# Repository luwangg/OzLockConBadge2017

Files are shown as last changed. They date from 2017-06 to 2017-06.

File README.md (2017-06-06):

# OzLockConBadge2017
Hardware and Firmware for the OzLockCon2017 Badge

Derived from the uDuck:
https://github.com/insecurityofthings/uDuck - as you can probably tell from the source code.

The hardware *may* support the uDuck firmware as the circuit is based off it - but i screwed something up and it doesn't want to work.
Ran out of time to debug so focused on the flashy flashy.

# Warning!
don't solder the USB connector onto the badge until you check the pin out! 
i screwed up and reversed the pads on the footprint - again...

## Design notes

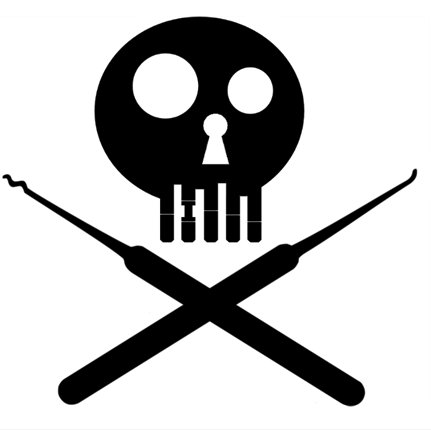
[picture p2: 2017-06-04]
hardware/OzLockCon.jpg

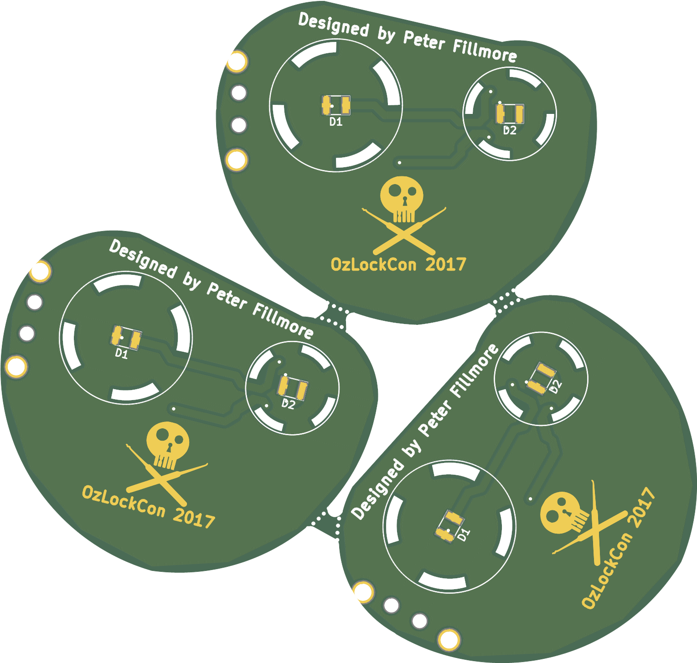
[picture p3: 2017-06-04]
hardware/Final/Final_Combined_Bottom.png

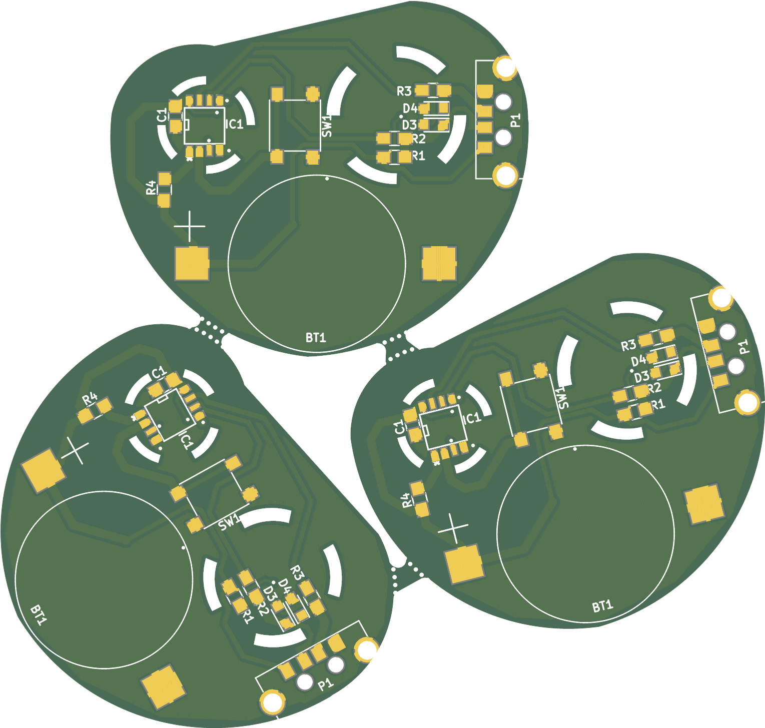
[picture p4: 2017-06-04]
hardware/Final/Final_Combined_Top.png

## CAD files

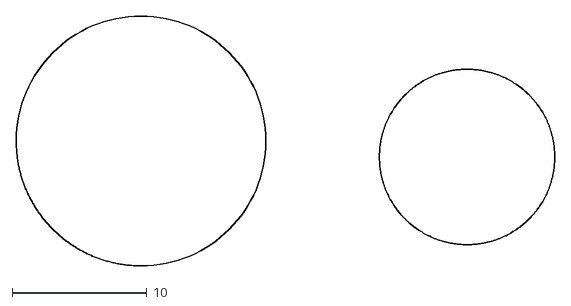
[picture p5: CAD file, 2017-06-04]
hardware/MechanicalView.dxf
40.0 x 18.5

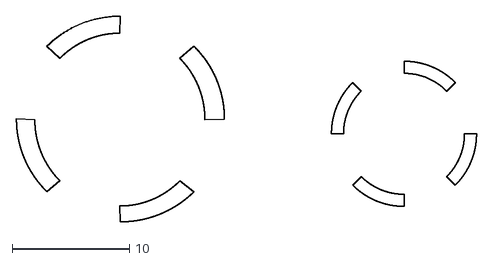
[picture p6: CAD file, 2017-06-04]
hardware/holes.dxf
39.2 x 17.5

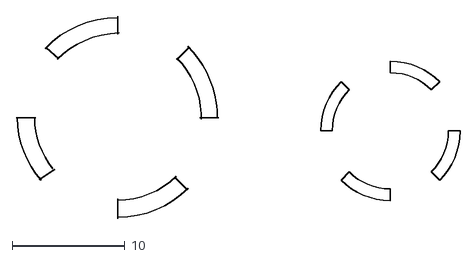
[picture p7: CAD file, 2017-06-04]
hardware/CutoutView.dxf
39.4 x 18.0

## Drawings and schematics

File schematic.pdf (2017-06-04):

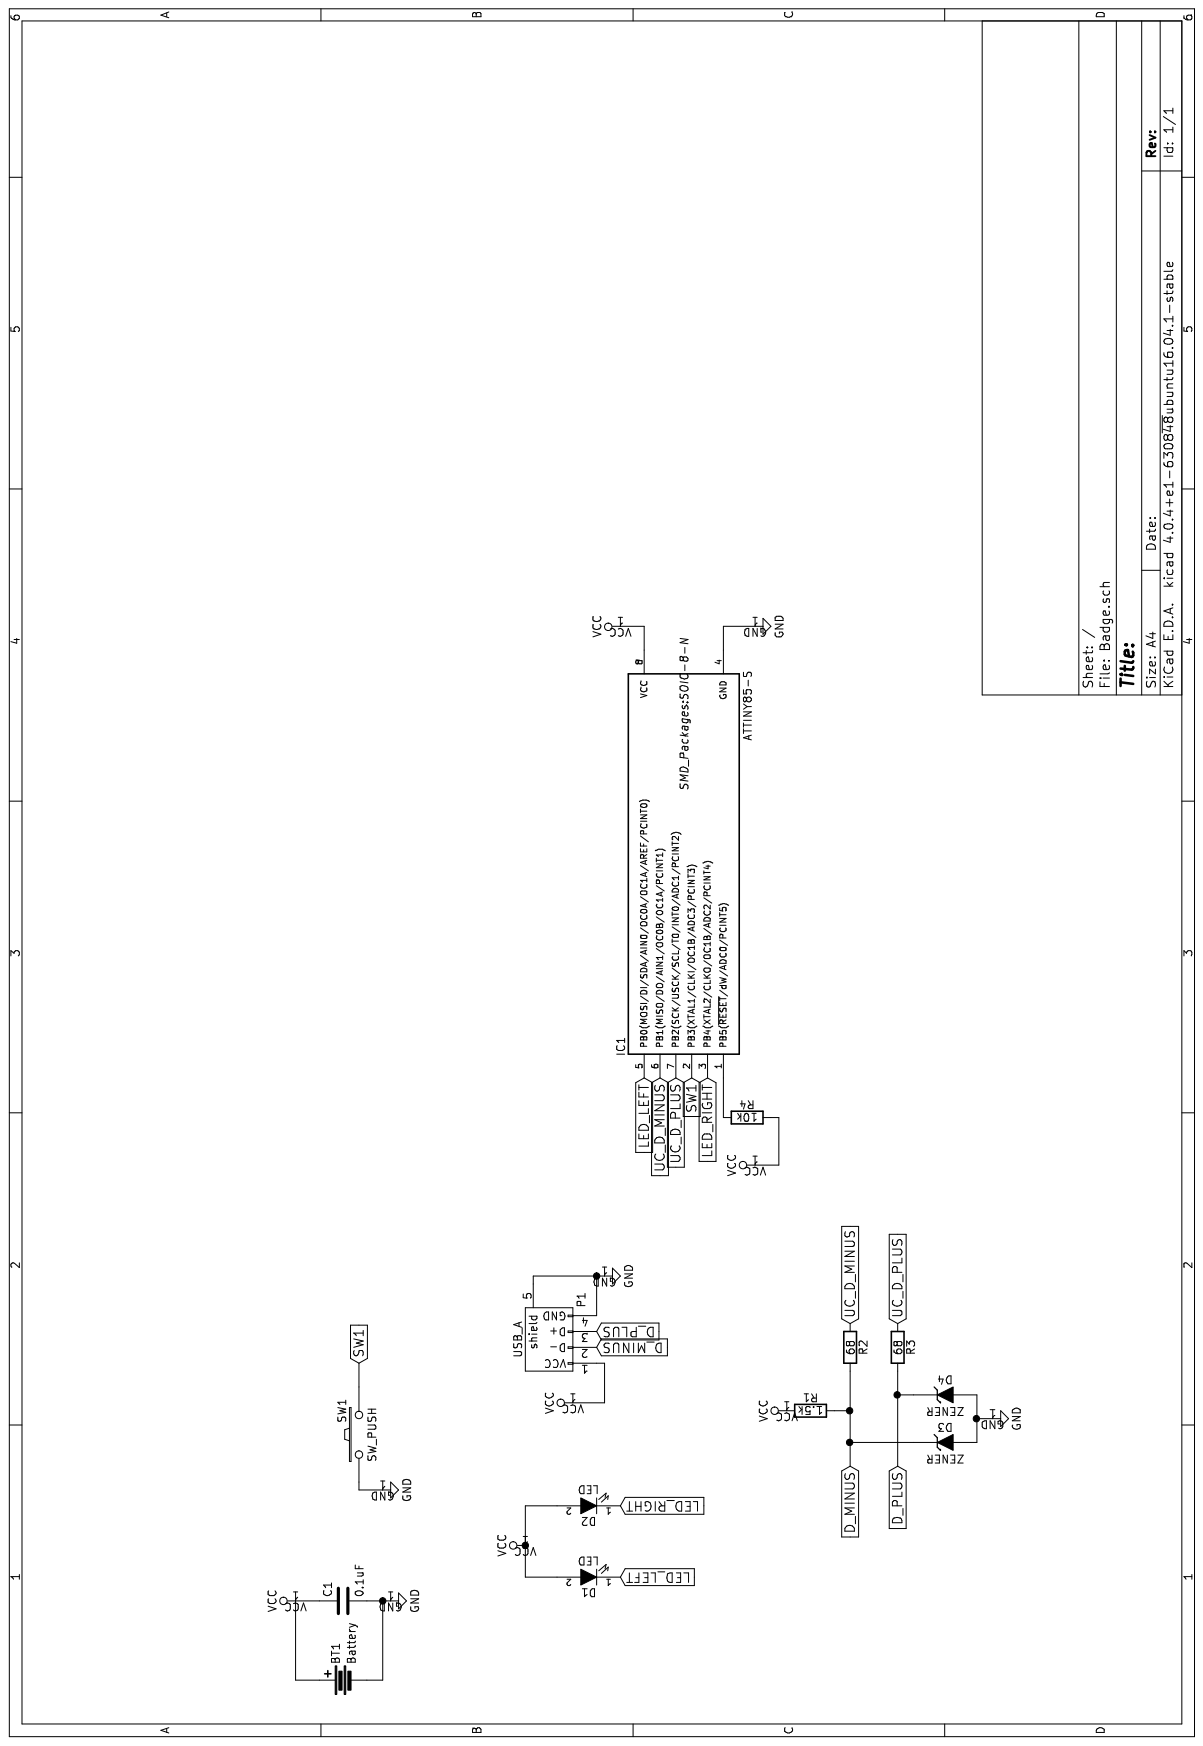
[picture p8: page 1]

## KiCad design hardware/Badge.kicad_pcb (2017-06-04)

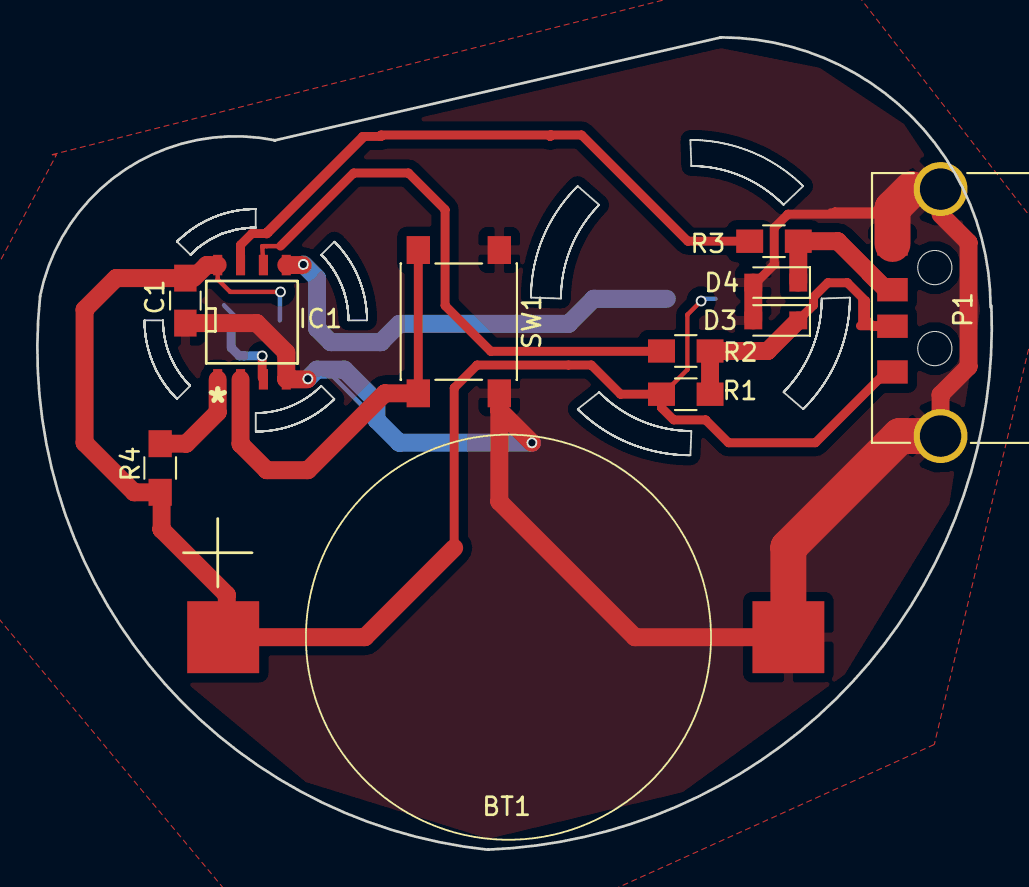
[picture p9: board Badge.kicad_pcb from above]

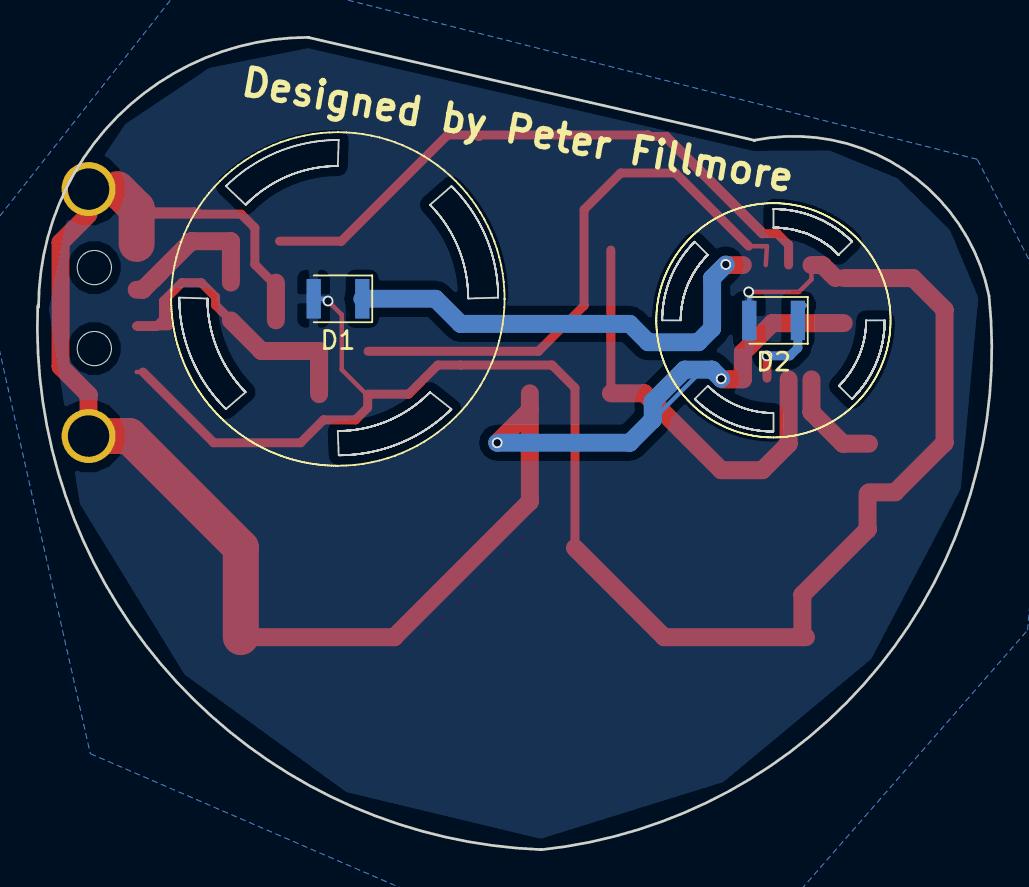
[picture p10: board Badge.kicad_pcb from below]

Board: 2 copper layers, 53.0 x 45.1 mm, 13 parts (2 on the bottom side), 10 nets.

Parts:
BT1: Battery; CR2032_SMD
C1: 0.1uF; C_0805_HandSoldering
D1, D2: LED; LED_3528
D3, D4: ZENER; D_SOD-323_HandSoldering
IC1: ATTINY85-S; SOIC-8-N
P1: USB_A; USB_A_SMD
R1: 1.5k; R_0805_HandSoldering
R2, R3: 68; R_0805_HandSoldering
R4: 10k; R_0805_HandSoldering
SW1: SW_PUSH; SW_SPST_PTS645

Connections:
D_MINUS: D3.1, P1.2, R1.2, R2.2
D_PLUS: D4.1, P1.3, R3.2
GND: BT1.2, C1.2, D3.2, D4.2, IC1.4, P1.4, P1.5, SW1.1
LED_LEFT: D1.1, IC1.5
LED_RIGHT: D2.1, IC1.3
unnamed: IC1.1, R4.1
SW1: IC1.2, SW1.2
UC_D_MINUS: IC1.6, R2.1
UC_D_PLUS: IC1.7, R3.1
VCC: BT1.1, C1.1, D1.2, D2.2, IC1.8, P1.1, R1.1, R4.2

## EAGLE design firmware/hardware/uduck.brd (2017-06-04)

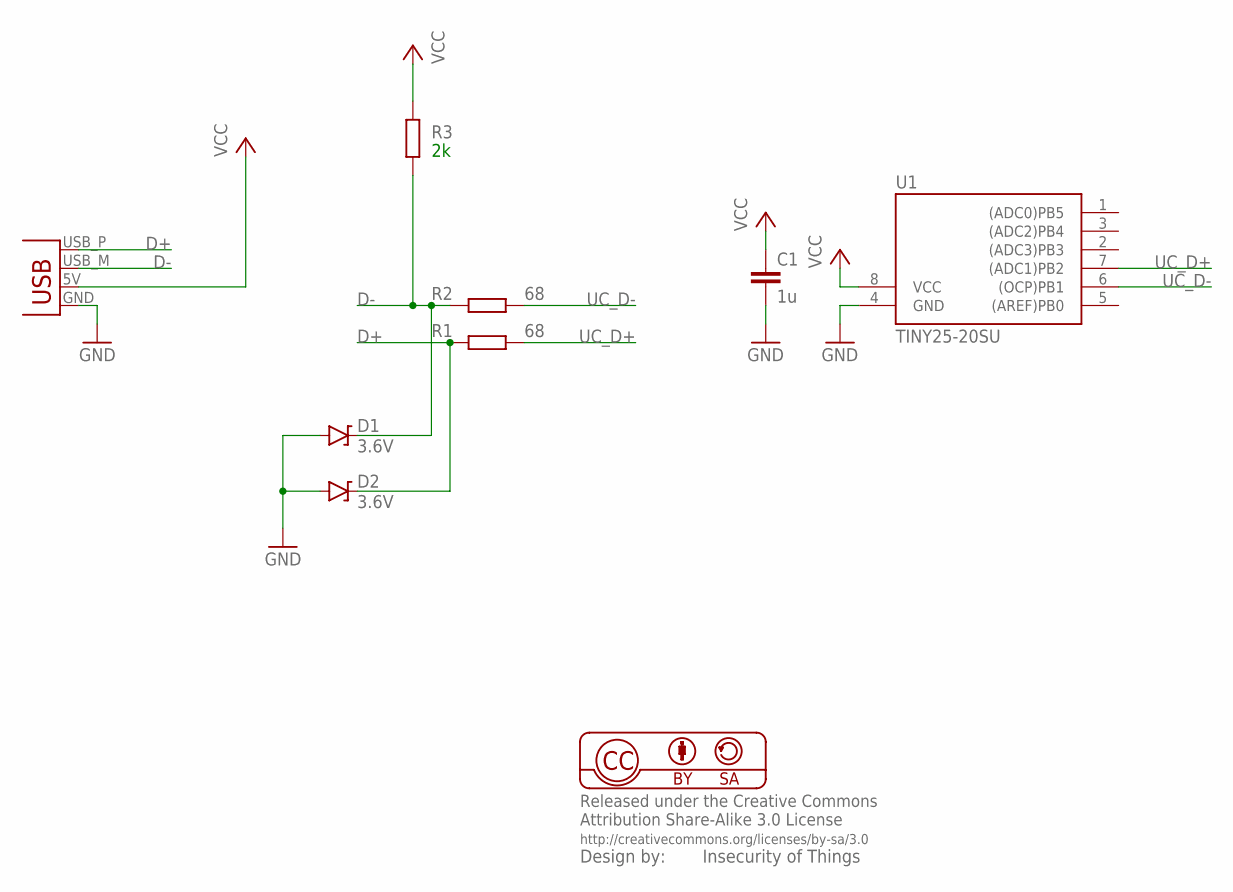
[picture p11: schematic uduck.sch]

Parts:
C1: 1u; C0805
D1, D2: 3.6V; SOD-323
R1, R2: 68; R0603
R3: 2k; R0603
U1: TINY25-20SU; SOIC8
X1: USBPCB; USB-A-PCB

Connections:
D+: D2.C, R1.2, X1.USB_P (D+)
D-: D1.C, R2.2, R3.1, X1.USB_M (D-)
GND: C1.2, D1.A, D2.A, U1.4 (GND), X1.GND
UC_D+: R1.1, U1.7 ((ADC1)PB2)
UC_D-: R2.1, U1.6 ((OCP)PB1)
VCC: C1.1, R3.2, U1.8 (VCC), X1.5V (VBUS)

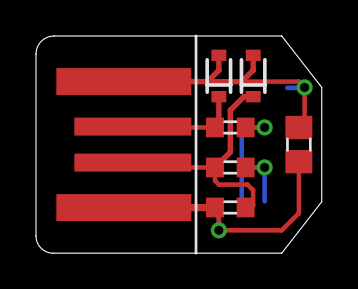
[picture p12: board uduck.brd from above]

Board: 2 copper layers, 15.9 x 12.1 mm, 8 parts (1 on the bottom side), 6 nets.

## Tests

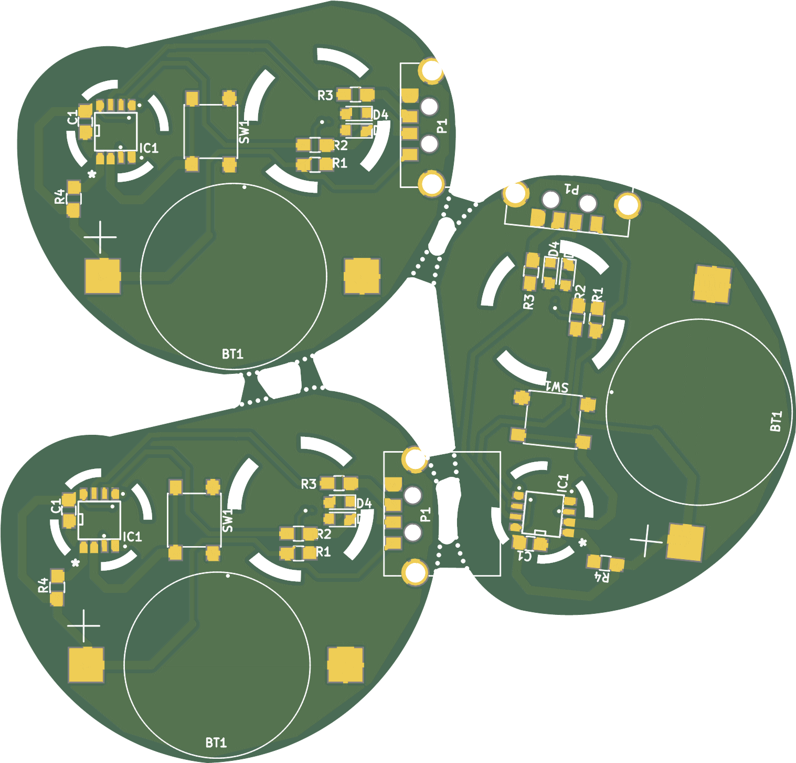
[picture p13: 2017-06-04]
hardware/Panelization/Test_Combined_Top.png

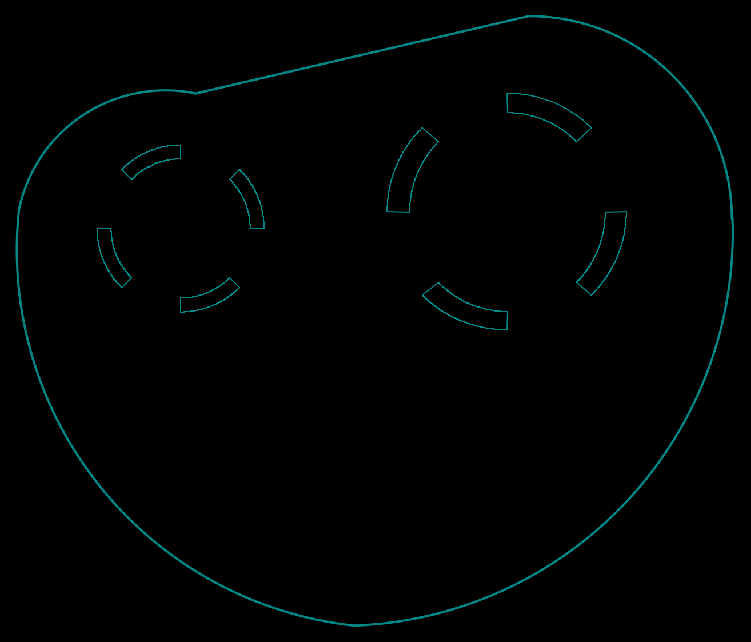
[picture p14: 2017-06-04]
hardware/Verification/edge.png

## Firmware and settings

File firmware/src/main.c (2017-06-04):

#include <avr/io.h>
#include <avr/wdt.h>
#include <avr/eeprom.h>
#include <avr/interrupt.h>
#include <avr/pgmspace.h>
#include <util/delay.h>
#include <stdlib.h>

//#include "usbdrv.h"
//#include "oddebug.h"

#define LED_LEFT 0b00000001
#define LED_RIGHT 0b00010000
#define SW1 0b00001000

volatile unsigned int mode_counter = 0;


ISR(PCINT0_vect) {
    //_delay_ms(50);   //wait for half second
   // PORTB ^= ~0b11101110;       //turn both LEDs off 
    if(mode_counter < 16) { 
        mode_counter++;
    }
    else{
        mode_counter = 0;
    }
    //PORTB ^=  0b00010001;       //turn LED off 
    _delay_ms(20); 
}

void setup() {
    GIMSK = 0b00100000;    // turns on pin change interrupts
    PCMSK = 0b00001000;    // turn on interrupts on pins PB3    
    sei();
    //DDRB = 0x00;         //PB as output
    //PORTB &= ~0x00;         //keep all LEDs off}
    DDRB |= _BV(PORTB0);         // OC0A
    //DDRB |= _BV(PORTB1);        // OC0B
    DDRB |= _BV(PORTB4);        // OC1B
    DDRB |= _BV(PORTB3);

    PORTB |= 0b00001000;         //enable pull-ups


  // Timer 0, Channel A
  TCCR0A = _BV(COM0A1) | _BV(WGM01) | _BV(WGM00);
  TCCR0B = _BV(CS00);
  //OCR0A = 128 * 0.75 - 1;     // Duty Cycle
  OCR0A = 256 * 0.99 - 1;     // Duty Cycle

  // Timer 0, Channel B
  //TCCR0A |= _BV(COM0B1);
  //OCR0B = 256 * 0.25 - 1;     // Duty Cycle

  // Timer 1
  TCCR1 = _BV(CS10);
  GTCCR = _BV(COM1B1) | _BV(PWM1B);
  //const uint8_t f = 38000;
  //OCR1C = 8000000.0 / f - 1;  // Frequency
  OCR1B = 256 * 0.99 - 1;     // Duty Cycle
  //OCR1B = f * 0.33;           // Duty Cycle    
}


int main(void)
{
    setup();
    PORTB &= ~0b11100110;       //turn both LEDs on
    uint8_t dir = 1;           // Direction 
    uint16_t stall = 0;        // Initial stall counter
    uint16_t stall_time = 20; // # of clocks to stall at top/bottom
    while(1)
    {
        switch(mode_counter){
           case 0: //low light
                OCR1B = 254;     // Duty Cycle
                OCR0A = 254;     // Duty Cycle
                break;
            case 1: //medium
                OCR1B = 250;     // Duty Cycle
                OCR0A = 250;     // Duty Cycle                PORTB |=  0b00011001;       //turn both LEDs on
                break;
            case 2:
                OCR1B = 127; 
                OCR0A = 127; 
                break;
            case 3: //low/high
                OCR1B = 254; 
                OCR0A = 220; 
                break; 
            case 4: 
                OCR1B = 254; 
                OCR0A = 220; 
                break;
            case 5: { //blink
                stall_time = 10; // # of clocks to stall at top/bottom             
                //sync eyes
                OCR0A = OCR1B;  
                // Stall at the top and bottom, and change direction
                if(OCR0A == 254 || OCR0A == 230) {
                    // Switch directon at top
                    if(OCR0A == 254) dir = -1;
                    else 
                    {   // Disable LED at bottom
                        // And switch direction
                        //DDRB  |= _BV(DDB0);
                        dir = 1; 
                    }
                    while(stall < stall_time) 
                    { 
                        ++stall;
                        _delay_ms(10); 
                    }
                    // Turn output back on if necessary
                    //if(OCR0A == 245) DDRB  &= ~(_BV(DDB0));
                    stall = 0;
                }
                // General case - increment direction either way
                    OCR0A += dir;
                    OCR1B += dir;
                }
                
                break; 
            case 6: //blink eyes alternatively
                stall_time = 10; // # of clocks to stall at top/bottom             
                //sync eyes
                OCR0A = OCR1B;  
                OCR0A = 254;
                OCR1B = 220; 
                stall = 0; 
                while(stall < stall_time/2){
                        ++stall;
                        _delay_ms(10);
                }
                OCR0A = 220;
                OCR1B = 254; 
                stall = 0; 
                while(stall < stall_time/2){
                        ++stall;
                        _delay_ms(10);
                }
                break; 
            case 7: //blink eyes alternatively
                stall_time = 5; // # of clocks to stall at top/bottom             
                //sync eyes
                OCR0A = OCR1B;  
                OCR0A = 254;
                OCR1B = 220; 
                stall = 0; 
                while(stall < stall_time/2){
                        ++stall;
                        _delay_ms(10);
                }
                OCR0A = 220;
                OCR1B = 254; 
                stall = 0; 
                while(stall < stall_time/2){
                        ++stall;
                        _delay_ms(10);
                }
                break; 
           case 8: //left eye only
               OCR0A = 254;
               OCR1B = 255;
               break;
           case 9: //left eye only
               OCR0A = 250;
               OCR1B = 255;
               break;
           case 10: //left eye only
               OCR0A = 220;
               OCR1B = 255;
               break;
           case 11: //right eye only
               OCR0A = 255;
               OCR1B = 250; 
               break;
           case 12: //right eye only
               OCR0A = 255;
               OCR1B = 220; 
               break;
           case 13: //right eye only
               OCR0A = 255;
               OCR1B = 220; 
               break;
           case 14:
               OCR0A = 255;
               OCR1B = 255; 
           default: //everything off
                    OCR0A = 255;
                    OCR1B = 255;
                    break;      
        }
        //DDRB = 0x00;         //PB as output
        //PORTB &= 0b00000000;       //turn LED off
        //_delay_ms(500);   //wait for half second
        //PORTB |= 0b11111111;       //turn LED on 
        //_delay_ms(500);   //wait for half second
    };        
    return 0;
}

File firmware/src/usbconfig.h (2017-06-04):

/* Name: usbconfig.h
 * Project: AVR USB driver
 * Author: Christian Starkjohann
 * Creation Date: 2007-06-23
 * Tabsize: 4
 * Copyright: (c) 2007 by OBJECTIVE DEVELOPMENT Software GmbH
 * License: GNU GPL v2 (see License.txt) or proprietary (CommercialLicense.txt)
 * This Revision: $Id: usbconfig.h 537 2008-02-28 21:13:01Z cs $
 */

#ifndef __usbconfig_h_included__
#define __usbconfig_h_included__

/* ---------------------------- Hardware Config ---------------------------- */

#define USB_CFG_IOPORTNAME      B
/* This is the port where the USB bus is connected. When you configure it to
 * "B", the registers PORTB, PINB and DDRB will be used.
 */
#define USB_CFG_DMINUS_BIT      2
/* This is the bit number in USB_CFG_IOPORT where the USB D- line is connected.
 * This may be any bit in the port.
 */
#define USB_CFG_DPLUS_BIT       1
/* This is the bit number in USB_CFG_IOPORT where the USB D+ line is connected.
 * This may be any bit in the port. Please note that D+ must also be connected
 * to interrupt pin INT0!
 */
#define USB_CFG_CLOCK_KHZ       (F_CPU/1000)
/* Clock rate of the AVR in MHz. Legal values are 12000, 16000 or 16500.
 * The 16.5 MHz version of the code requires no crystal, it tolerates +/- 1%
 * deviation from the nominal frequency. All other rates require a precision
 * of 2000 ppm and thus a crystal!
 * Default if not specified: 12 MHz
 */

/* ----------------------- Optional Hardware Config ------------------------ */

/* #define USB_CFG_PULLUP_IOPORTNAME   D */
/* If you connect the 1.5k pullup resistor from D- to a port pin instead of
 * V+, you can connect and disconnect the device from firmware by calling
 * the macros usbDeviceConnect() and usbDeviceDisconnect() (see usbdrv.h).
 * This constant defines the port on which the pullup resistor is connected.
 */
/* #define USB_CFG_PULLUP_BIT          4 */
/* This constant defines the bit number in USB_CFG_PULLUP_IOPORT (defined
 * above) where the 1.5k pullup resistor is connected. See description
 * above for details.
 */

/* --------------------------- Functional Range ---------------------------- */

#define USB_CFG_HAVE_INTRIN_ENDPOINT    1
/* Define this to 1 if you want to compile a version with two endpoints: The
 * default control endpoint 0 and an interrupt-in endpoint 1.
 */
#define USB_CFG_HAVE_INTRIN_ENDPOINT3   0
/* Define this to 1 if you want to compile a version with three endpoints: The
 * default control endpoint 0, an interrupt-in endpoint 1 and an interrupt-in
 * endpoint 3. You must also enable endpoint 1 above.
 */
#define USB_CFG_IMPLEMENT_HALT          0
/* Define this to 1 if you also want to implement the ENDPOINT_HALT feature
 * for endpoint 1 (interrupt endpoint). Although you may not need this feature,
 * it is required by the standard. We have made it a config option because it
 * bloats the code considerably.
 */
#define USB_CFG_INTR_POLL_INTERVAL      10
/* If you compile a version with endpoint 1 (interrupt-in), this is the poll
 * interval. The value is in milliseconds and must not be less than 10 ms for
 * low speed devices.
 */
#define USB_CFG_IS_SELF_POWERED         0
/* Define this to 1 if the device has its own power supply. Set it to 0 if the
 * device is powered from the USB bus.
 */
#define USB_CFG_MAX_BUS_POWER           50
/* Set this variable to the maximum USB bus power consumption of your device.
 * The value is in milliamperes. [It will be divided by two since USB
 * communicates power requirements in units of 2 mA.]
 */
#define USB_CFG_IMPLEMENT_FN_WRITE      0
/* Set this to 1 if you want usbFunctionWrite() to be called for control-out
 * transfers. Set it to 0 if you don't need it and want to save a couple of
 * bytes.
 */
#define USB_CFG_IMPLEMENT_FN_READ       0
/* Set this to 1 if you need to send control replies which are generated
 * "on the fly" when usbFunctionRead() is called. If you only want to send
 * data from a static buffer, set it to 0 and return the data from
 * usbFunctionSetup(). This saves a couple of bytes.
 */
#define USB_CFG_IMPLEMENT_FN_WRITEOUT   0
/* Define this to 1 if you want to use interrupt-out (or bulk out) endpoint 1.
 * You must implement the function usbFunctionWriteOut() which receives all
 * interrupt/bulk data sent to endpoint 1.
 */
#define USB_CFG_HAVE_FLOWCONTROL        0
/* Define this to 1 if you want flowcontrol over USB data. See the definition
 * of the macros usbDisableAllRequests() and usbEnableAllRequests() in
 * usbdrv.h.
 */
#ifndef __ASSEMBLER__
extern void usbEventResetReady(void);
#endif
#define USB_RESET_HOOK(isReset)             if(!isReset){usbEventResetReady();}
/* This macro is a hook if you need to know when an USB RESET occurs. It has
 * one parameter which distinguishes between the start of RESET state and its
 * end.
 */
#define USB_CFG_HAVE_MEASURE_FRAME_LENGTH   1
/* define this macro to 1 if you want the function usbMeasureFrameLength()
 * compiled in. This function can be used to calibrate the AVR's RC oscillator.
 */
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

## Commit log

2017-06-04 inital commit
    [Badge.kicad_pcb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]
2017-06-04 now with added schematic

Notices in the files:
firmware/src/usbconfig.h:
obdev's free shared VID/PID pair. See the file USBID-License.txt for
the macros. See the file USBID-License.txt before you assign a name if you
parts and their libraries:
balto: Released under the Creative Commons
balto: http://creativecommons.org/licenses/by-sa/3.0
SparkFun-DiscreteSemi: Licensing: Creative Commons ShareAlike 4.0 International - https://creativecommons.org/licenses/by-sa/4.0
